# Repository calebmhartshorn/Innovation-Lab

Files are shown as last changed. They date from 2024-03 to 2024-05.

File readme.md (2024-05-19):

# QuarterMaster
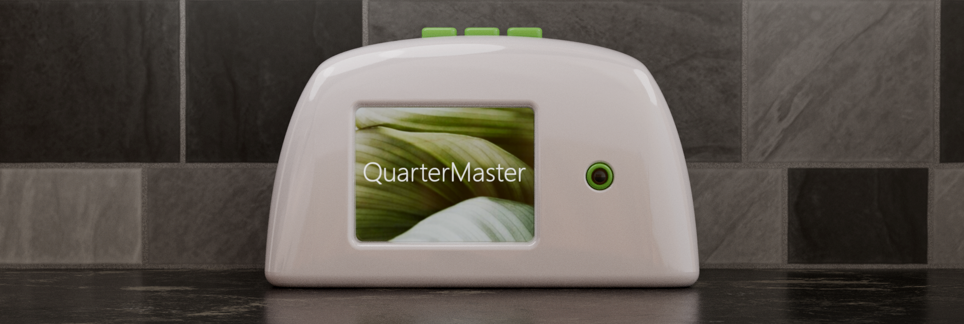
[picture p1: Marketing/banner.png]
QuarterMaster Banner Image

QuarterMaster is a smart kitchen device used to track grocery inventory, expiration dates, and suggest recipes to minimize food waste.

More details can be found at our [website](https://oliverstratford23.wixsite.com/quartermaster).

### QuarterMaster Repository Structure
Current development work is organized as follows:

| Directory | Info |
|--|--|
| `/App` | Holds all server-side files for the Raspberry Pi |
| `/App/website` | Holds all client-side web app files |
| `/CAD` | Holds any CAD and STL files, parts lists, and assembly instructions. |
| `/Marketing` | Holds marketing briefs, website files, blender files/renders, etc. |

### Client and Server Info
The physical scanner device, running on a RPi, hosts a local HTTP webserver allowing clients to connect directly via IP address on port 8000.
For example, if the RPi's local IP address was 192.168.0.14, another device on the same network could access the webclient via http://192.168.0.14:8000. Note this does not work on networks with certain firewalls/restrictions (notably including Bath Spa `eduroam` and similar networks, depending on subdomain allocations). It is expected to work on most home networks.

> **Note:** Port number may be redefined in server.py

For reference during development, the following figure summarizes the platforms, languages, and responsibilities of each entity.

|| Client | Server |
|--|--|--|
| **Platform** | Mobile/Desktop Browser | Raspberry Pi 5 |
| **Languages** | <li>HTML</li><li>CSS</li><li>JS</li> | Python
| **Features** |<li>Inventory Viewing</li><li>Recipe Viewing</li> | <li>Scan Items In</li><li>Scan Items Out</li>

### Communications Protocol
Client ↔ Server communication uses HTTP protocol. Specifically, GET and POST requests are made by the client.
> This functionality is implemented in `/App/server.py` and `/App/website/client.js`

| Type | Path | Body | Response Content Type| Response | Note|
|--|--|--|--|--|--|
| `GET` | `/index.html` | |  `text/html`  | `index.html` file |
| `GET` | `/styles.css` || `text/css`  | `styles.css` file |
| `GET` | `/client.js` | |`application/javascript`  | `client.js` file |
| ... | ... | ... | ... | ...| Continued for any additional plain files
| `GET` | `/inventory` || `application/javascript` | JSON inventory data | |
| `GET` | `/recipe/*` || `application/javascript` | Makes request to Tesco API and returns result. | See `server.py` line 180-225 for additional parameter details.
| `POST` | `/update-inventory` | Updated JSON inventory data | `text/html` | Status Message | Current web app version does not implement this functionality.

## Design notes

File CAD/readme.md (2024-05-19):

## CAD

STL files for product model.

Exportable CAD files can be viewed on [OnShape](https://cad.onshape.com/documents/a9ea1d888f3dee972e6036d2/w/ec1619c3bd35b931f617c110/e/a813004631bccc3c93063bfe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)

### Assembly Instructions:

After all the parts have been printed using the given STLs the assembly proccess can begin

Step #1: Attach the screen to the mounting frame using the smaller bushings with a nylon nut and bolt.

Step #2: Connect the screen to the Raspberry Pi following the screens wiki page (https://www.waveshare.com/wiki/2.4inch_LCD_Module).

Step #3: Attach the camera to the mounting frame using the longer bushing with a nylon nut and bolt.

Step #4: Attach the camera cable adapter to the Raspberry Pi using the camera port 0, and the camera

Step #5: Ensure the SD card has been placed within the Raspberry Pi.

Step #6: Thread a screw through the back casing, the Raspberry Pi, and mounting frame and secure this with a nut. 

Step #7: Next, clip the buttons into there slot, located at the top of the back casing. 

Step #8: Wire these buttons into GPIO ports 14, 15, and 17.

Step #9: The printed buttons can then be glued onto these buttons.

Step #10: Place a nylon nut in each cut out in the front casing.

Step #11: Thread a screw through the back of the back casing into the nylon nut of the front casing to secure the whole product together. 

### Components:

Screen: https://thepihut.com/products/2-4-lcd-display-module-240x320

SD Card: https://www.samsung.com/uk/memory-storage/memory-card/evo-plus-microsd-card-64gb-mb-mc64sa-eu/

Camera Adapter Cable: https://thepihut.com/products/camera-adapter-cable-for-raspberry-pi-5?variant=42531560784067

Camera: https://www.amazon.co.uk/gp/product/B076FB1KCW/ref=ox_sc_act_title_2?smid=A1X7QLRQH87QA3&th=1

Buttons: https://thepihut.com/products/soft-silicone-top-6mm-push-buttons-20-pack?variant=19932900720702

Nuts: https://thepihut.com/products/nylon-nut-m2-5?variant=20063144869950

Screws: https://thepihut.com/products/nylon-slotted-cheese-head-screws-m2-5-x-20mm?variant=20063144935486

Cables: https://www.amazon.co.uk/AZDelivery-Pieces-Jumper-Arduino-Raspberry/dp/B074P726ZR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

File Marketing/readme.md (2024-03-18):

### Marketing

Keep any files for marketing material here. This includes logos, website files, etc.

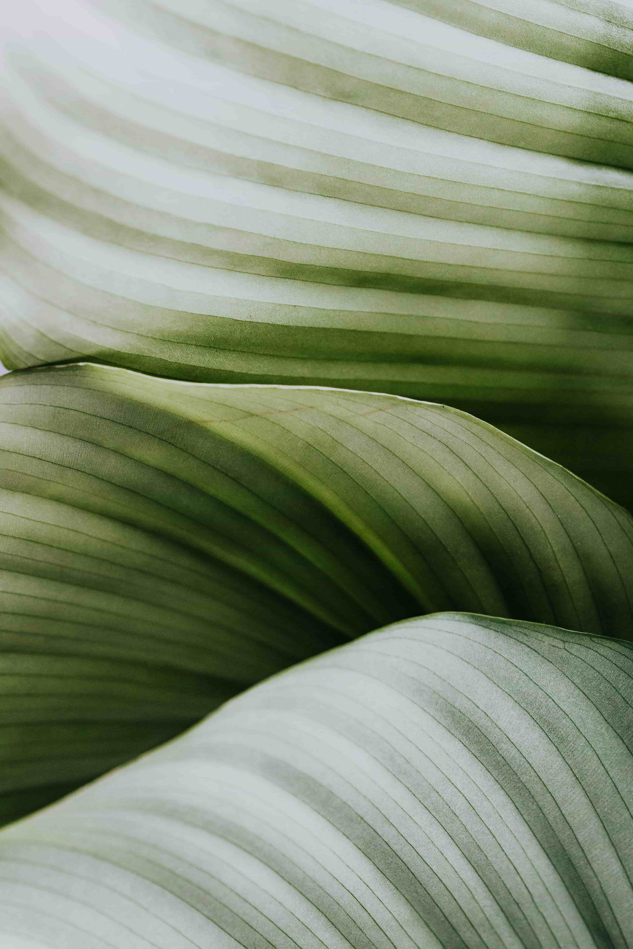
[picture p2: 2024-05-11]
App/website/assets/leaf.jpg

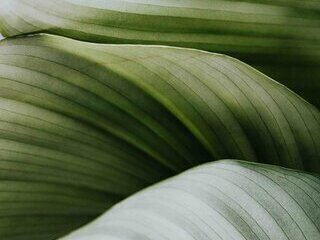
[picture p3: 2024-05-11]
App/leaf_320x240.jpg

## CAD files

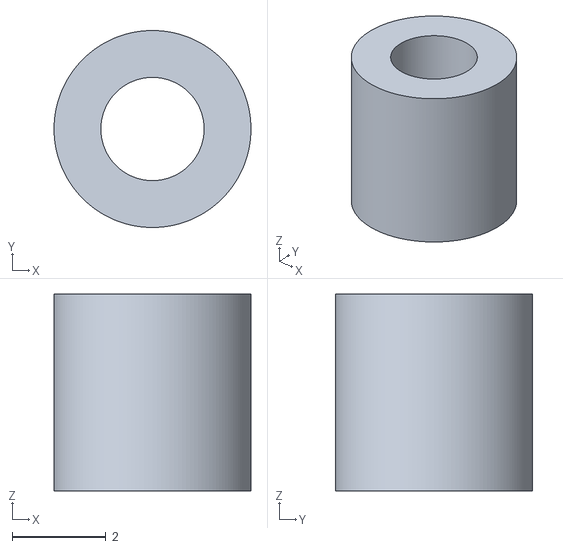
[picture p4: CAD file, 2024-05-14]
CAD/2x_Bushing_2.2x4.2.stl
4.20 x 4.20 x 4.20

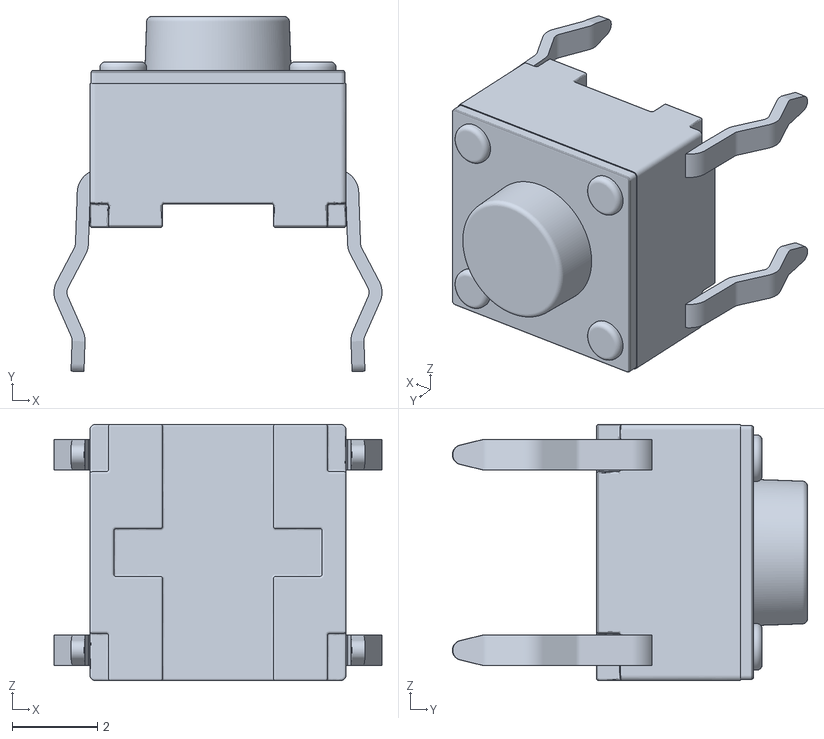
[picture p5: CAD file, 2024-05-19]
CAD/electronics/tactileswitch-short.stl
7.69 x 8.33 x 6.01

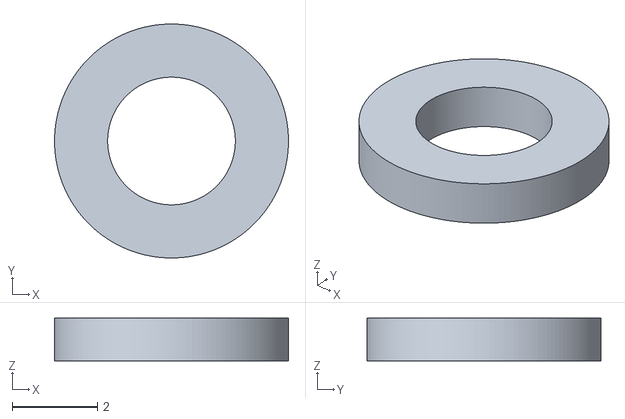
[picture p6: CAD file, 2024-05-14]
CAD/4x_Bushing_3.0x1.0.stl
5.50 x 5.50 x 1.00

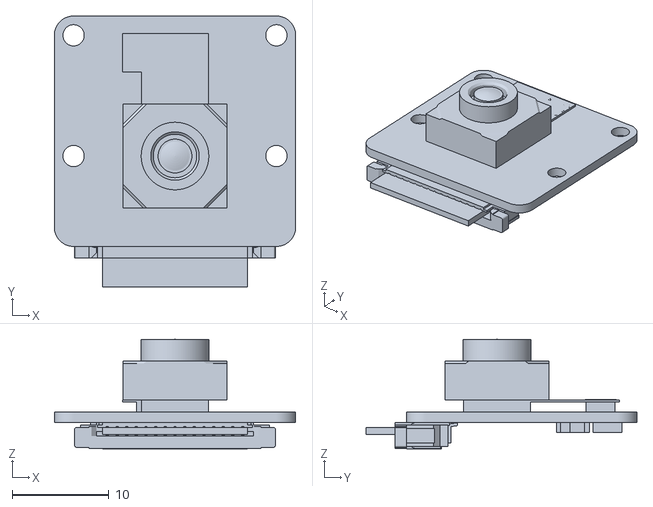
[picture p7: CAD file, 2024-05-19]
CAD/electronics/Camera Moudule 3 v8 (1).stl
25.0 x 28.1 x 11.3

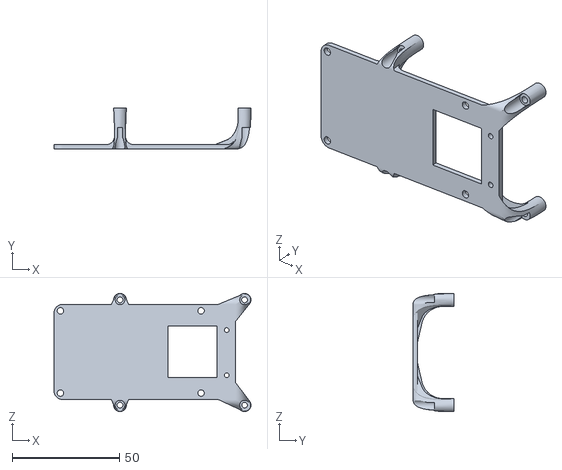
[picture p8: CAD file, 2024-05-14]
CAD/1x_Mounting_Frame.stl
91.7 x 19.1 x 55.0

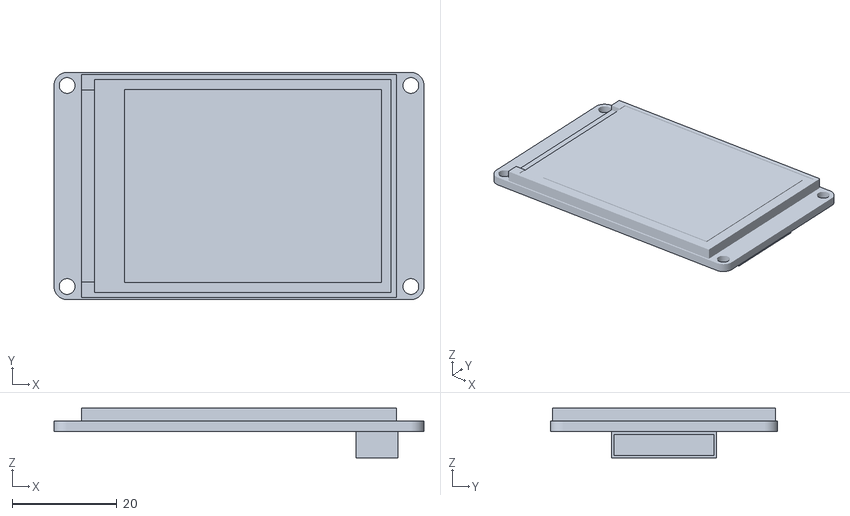
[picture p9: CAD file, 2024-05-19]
CAD/electronics/LCD.stl
70.5 x 43.3 x 9.50

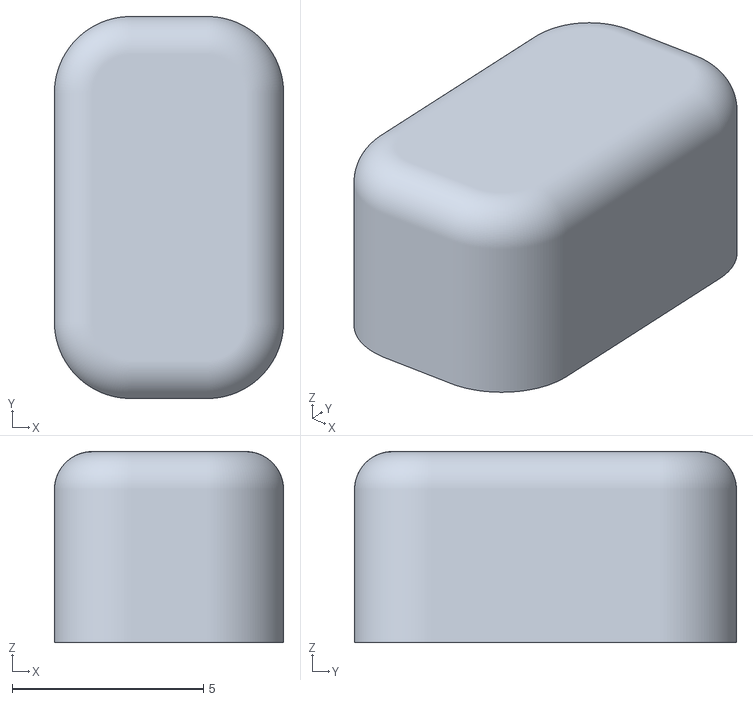
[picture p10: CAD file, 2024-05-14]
CAD/3x_Button.stl
6.00 x 10.0 x 5.00

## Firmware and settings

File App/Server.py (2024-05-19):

# import OS and set environment variables
import os
os.environ['XDG_RUNTIME_DIR'] = '/tmp/runtime-user/' # Set root working dir
os.environ['LIBCAMERA_LOG_LEVELS'] = '4'             # Hide libcamera logs
os.environ['PYGAME_HIDE_SUPPORT_PROMPT'] = '1'       # Hide pygame messages

# Default Libs
import time, datetime, threading, http.server, socketserver, json, logging, requests
from urllib.parse import urlparse, parse_qs

# Non-default Libs
import cv2                                   # OpenCV - For vision processing 
from pyzbar.pyzbar import decode, ZBarSymbol # Pyzbar - For barcode reading
from picamera2 import Picamera2              # Picamera2 - RPi Camera drivers
import pygame                                # pygame - For sound effects

# Local files
from gui_app import App, State

# Setup logging
logger = logging.getLogger('simple_example')
logger.setLevel(logging.DEBUG)
console = logging.StreamHandler()
console.setLevel(level=logging.DEBUG)
formatter =  logging.Formatter('%(levelname)s : %(message)s')
console.setFormatter(formatter)
logger.addHandler(console)

# Globals
HTTP_SERVER_PORT = 8000

inventory = {}
app = None

def add_quantity(barcode):
    barcode = str(barcode)
    scanned_date = datetime.datetime.now().strftime("%Y-%m-%d")
    
    if barcode in inventory:
        inventory_entry = inventory[barcode]
        inventory_entry['scans'].append(scanned_date)
    else:
        inventory[barcode] = {
            "name": "Unknown",
            "generic_name": "Unknown",
            "size": 1,
            "size_units": "Unit",
            "shelf_life": 7,
            "scans": [scanned_date]
        }

    with open('inventory.json', 'w') as f:
        json.dump(inventory, f, indent=2)
    app.init_main_scanned_state(barcode)

def remove_quantity(barcode):
    barcode = str(barcode)    
    if barcode in inventory:
        inventory_entry = inventory[barcode]
        if len(inventory_entry['scans']) > 0:
            inventory_entry['scans'].pop(0)
            with open('inventory.json', 'w') as f:
                json.dump(inventory, f, indent=2)
    app.init_scan_out_scanned_state(barcode)
    
def decode_barcode_from_webcam():
    global app

    cv2.namedWindow('image',cv2.WINDOW_GUI_NORMAL)
    
    Picamera2.set_logging(Picamera2.ERROR)
    picam2 = Picamera2()
    
    config = picam2.create_still_configuration(
        main = {"size": picam2.sensor_resolution}
    )
    picam2.configure(config)
    picam2.set_controls({"ExposureTime": 5000, "AnalogueGain": 50.0})
    picam2.start()
    
    pygame.mixer.pre_init(frequency=44100, size=-16, channels=2)
    pygame.mixer.init()
    sound = pygame.mixer.Sound('blip-131856.mp3')
    
    while True:
        if app.state == State.SLEEP:
            continue

        frame = picam2.capture_array()

        scale = 0.2
        width = int(frame.shape[1] * scale)
        height = int(frame.shape[0] * scale)
        frame = cv2.resize(frame, (width, height))
        
        frame = cv2.cvtColor(frame, cv2.COLOR_BGR2GRAY)
        
        decoded_objects = decode(frame, symbols=[ZBarSymbol.EAN8])

        for obj in decoded_objects:
            barcode = obj.data.decode('utf-8')

            try:
                barcode_int = int(barcode)
            except ValueError:
                print(f"Invalid barcode: {barcode}")
                continue


            try:
                if app.state == State.MAIN:
                    add_quantity(barcode_int)
                    app.no_input_ts = datetime.datetime.now()
                    playing = sound.play()
                    time.sleep(.5)
                elif app.state == State.SCAN_OUT:
                    remove_quantity(barcode_int)
                    app.no_input_ts = datetime.datetime.now()                    
                    playing = sound.play()
                    time.sleep(.5)
            except Exception as e:
                print(f"Error adding barcode to inventory: {e}")

            cv2.rectangle(frame, (obj.rect.left, obj.rect.top),
                          (obj.rect.left + obj.rect.width, obj.rect.top + obj.rect.height),
                          (0, 255, 0), 2)
            cv2.putText(frame, str(barcode_int), (obj.rect.left, obj.rect.top - 10),
                        cv2.FONT_HERSHEY_SIMPLEX, 0.5, (0, 0, 255), 2)

        cv2.imshow('image', frame)

        if cv2.waitKey(1) & 0xFF == 27:
            break

    cv2.destroyAllWindows()

class MyHTTPRequestHandler(http.server.SimpleHTTPRequestHandler):
    def set_common_headers(self):
        self.send_header('Access-Control-Allow-Origin', '*')
        self.send_header('Access-Control-Allow-Methods', 'GET, POST, OPTIONS')
        self.end_headers()
    def do_GET(self):
        global inventory
        print("Received GET request")
        try:
            if self.path == '/':
                self.send_response(200)
                self.send_header('Content-type', 'text/html')
                self.end_headers()
                with open('website/index.html', 'rb') as f:
                    self.wfile.write(f.read())
            elif self.path == '/client.js':
                self.send_response(200)
                self.send_header('Content-type', 'text/javascript')
                self.end_headers()
                with open('website/client.js', 'rb') as f:
                    self.wfile.write(f.read())
            elif self.path == '/styles.css':
                self.send_response(200)
                self.send_header('Content-type', 'text/css')
                self.end_headers()
                with open('website/styles.css', 'rb') as f:
                    self.wfile.write(f.read())
            elif self.path == '/Assets/leaf.jpg':
                self.send_response(200)
                self.send_header('Content-type', 'text/javascript')
                self.end_headers()
                with open('website/assets/leaf.jpg', 'rb') as f:
                    self.wfile.write(f.read())
            elif self.path == '/inventory':
                print("Received request for inventory data")
                self.send_response(200)
                self.send_header('Content-type', 'application/json')
                self.end_headers()
                inventory_data = json.dumps(inventory).encode()
                print(f"Sending inventory data")
                self.wfile.write(inventory_data)


            elif self.path.startswith("/recipe"):
                # Parse the URL
                parsed_url = urlparse(self.path)
                
                # Extract the query parameters
                params = parse_qs(parsed_url.query)
                
                # Now you can access the parameters as a dictionary
                ingredients =          params.get('ingredients',['[]'])[0].replace("[", "").replace("]", "").split(",")
                mandatoryIngredients = params.get('must', [])
                if mandatoryIngredients:
                    mandatoryIngredients = [mandatoryIngredients[0]]
                else:
                    mandatoryIngredients = []  # Set it to an empty list if 'must' is not in the query

                url = 'https://realfood.tesco.com/api/ingredientsearch/getrecipes'
                
                data = {
                    # These are a harcoded example. Anything is fine, but make to use at least 3 ingredients and only use terms defined
                    # in ingredients.txt
                    'ingredients': ingredients,
                    'mandatoryIngredients': mandatoryIngredients,
                    'dietaryRequirements': []
                }
                response = requests.post(url, json=data)

                json_data = response.json()
                print(json.dumps(json_data, indent=2))

                # Just names
                response = ""
                for recipe in json_data['results']:
                    name = recipe['recipeName']
                    response += f"<p>{name}</p>"
                    #print(f"{name}")
                self.send_response(200)
                self.send_header('Content-type', 'application/json')
                self.set_common_headers()
                self.wfile.write(json.dumps(json_data).encode())


            else:
                super().do_GET()
        except Exception as e:
            print(f"Error in do_GET: {e}")
            self.send_error(500, str(e))

    def do_POST(self):
        try:
            if self.path == '/update-inventory':
                content_length = int(self.headers['Content-Length'])
                post_data = self.rfile.read(content_length)
                updated_inventory = json.loads(post_data.decode('utf-8'))
                global inventory
                inventory = updated_inventory
                self.send_response(200)
                self.send_header('Content-type', 'text/plain')
                self.end_headers()
                self.wfile.write(b'Inventory updated successfully')
            else:
                super().do_POST()
        except Exception as e:
            print(f"Error in do_POST: {e}")
            self.send_error(500, str(e))

def main():
    global inventory, app
    
    # Read in inventory
    if os.path.exists('inventory.json'):
        with open('inventory.json', 'r', encoding='UTF-8') as f:
            inventory = json.load(f)
    else:
        print("File 'inventory.json' not found. Creating a new one.")
        inventory = {}
    class MyTCPServer(socketserver.TCPServer):
        allow_reuse_address = True
    with MyTCPServer(("", HTTP_SERVER_PORT), MyHTTPRequestHandler) as httpd:
        # Instantiate GUI app
        app = App(logger, inventory)
        
        # Create thread objects
        app_thread = threading.Thread(target=app.start)
        http_server_thread = threading.Thread(target=httpd.serve_forever)
        
        # Start threads
        app_thread.start()
        http_server_thread.start()

        decode_barcode_from_webcam()

        # Terminate & join remaining threads
        app.shutdown()
        httpd.shutdown()
        app_thread.join()
        http_server_thread.join()

if __name__ == "__main__":
    main()

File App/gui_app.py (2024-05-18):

#!/usr/bin/python
# -*- coding: UTF-8 -*-
#import chardet
import sys, logging, math, time
from enum import Enum
from datetime import datetime, timedelta
import os
# Gets the current user's home directory so it could be pi or Matt or whatever
home_dir = os.path.expanduser('~')
lg_folder = os.path.join(home_dir, 'lg-master', 'LCD_Module_RPI_code', 'RaspberryPi', 'python')
sys.path.append(lg_folder)
from lib import LCD_2inch4
import gpiozero
from PIL import Image,ImageDraw,ImageFont, ImageEnhance
import queue  # Import the queue module


class State(Enum):
    WELCOME = 0
    MAIN = 1
    SCAN_OUT = 2
    MAIN_SCANNED = 3
    SCAN_OUT_SCANNED = 4
    SLEEP = 5

class App():

    def __init__(self, logger, inventory):

        self.logger = logger    
        self.inventory = inventory

        # LCD pins
        RST = 27
        DC = 25
        BL = 18
        bus = 0 
        device = 0
        
        self.lcd = LCD_2inch4.LCD_2inch4()

        # Initialize library.
        self.lcd.Init()



        # Setup buttons
        PIN_BTN_LEFT = 15
        PIN_BTN_RIGHT = 17
        PIN_BTN_MIDDLE = 14
        self.btn_left = gpiozero.Button(PIN_BTN_LEFT, bounce_time=0.05)
        self.btn_right = gpiozero.Button(PIN_BTN_RIGHT, bounce_time=0.05)
        self.btn_middle = gpiozero.Button(PIN_BTN_MIDDLE, bounce_time=0.05)
        self.commands_queue = queue.Queue()  # Define a queue for commands

        self.btn_left.when_pressed = lambda: self.commands_queue.put(('left',))
        self.btn_right.when_pressed = lambda: self.commands_queue.put(('right',))
        self.btn_middle.when_pressed = lambda: self.commands_queue.put(('middle',))

        self.is_btn_left_just_pressed = False
        self.is_btn_right_just_pressed = False
        self.is_btn_middle_just_pressed = False

        self.no_input_ts = datetime.now()

        self.font1 = ImageFont.truetype("Font00.ttf",48)

        self.exit = False

        self.init_welcome_state()

    def init_welcome_state(self):
        self.state = State.WELCOME
        self.welcome_text_y = 240
        self.welcome_start_ts = datetime.now()

        #Set the backlight to 100
        self.lcd.bl_DutyCycle(100)
#        self.lcd.clear()

    def init_main_state(self):
        self.state = State.MAIN
        self.menu_scroll_position = 0
        self.menu_cursor_position = 0
        self.no_input_ts = datetime.now()

    def init_scan_out_state(self):
        self.state = State.SCAN_OUT

    def init_main_scanned_state(self, barcode):
        self.state = State.MAIN_SCANNED
        self.scanned_item_name = self.inventory[barcode]["name"]
        self.scanned_start_ts = datetime.now()

    def init_scan_out_scanned_state(self, barcode):
        self.state = State.SCAN_OUT_SCANNED
        self.scanned_item_name = self.inventory[barcode]["name"]
        self.scanned_start_ts = datetime.now()

    def init_sleep_state(self):
        self.state = State.SLEEP
        #Set the backlight to 0
        self.lcd.bl_DutyCycle(0)

    def start(self):
        while self.exit == False:
            self.update_inputs()
            self.update()
            self.render()
    
    def shutdown(self):
        self.exit = True
    
    def update_inputs(self):
        self.is_btn_left_just_pressed = False
        self.is_btn_right_just_pressed = False
        self.is_btn_middle_just_pressed = False
        while not self.commands_queue.empty(): 
            self.no_input_ts = datetime.now()
            command = self.commands_queue.get()
            if command[0] == 'left':
                self.is_btn_left_just_pressed = True
            elif command[0] == 'right':
                self.is_btn_right_just_pressed = True
            elif command[0] == 'middle':
                self.is_btn_middle_just_pressed = True
        self.sec_since_last_input = (datetime.now() - self.no_input_ts).seconds

    def update(self):
        match self.state:
            case State.WELCOME:
                self.welcome_text_y += (120 - self.welcome_text_y) * 0.25
                ellapsed_time = datetime.now() - self.welcome_start_ts
                if ellapsed_time.seconds > 1:
                    self.init_main_state()
            case State.MAIN:
                if self.is_btn_left_just_pressed:
                    self.menu_cursor_position -= 1  # Move up in the list
                    if self.menu_cursor_position < 0:
                        self.menu_cursor_position = 0  # Ensure the position doesn't go below 0
                    if self.menu_scroll_position > self.menu_cursor_position:
                        self.menu_scroll_position = self.menu_cursor_position
                if self.is_btn_right_just_pressed:
                    self.menu_cursor_position += 1  # Move down in the list
                    length = len(self.process_items())
                    if self.menu_cursor_position > length - 1:
                        self.menu_cursor_position = length - 1
                    if self.menu_scroll_position + 4 < self.menu_cursor_position:
                        self.menu_scroll_position = self.menu_cursor_position - 4
                if self.is_btn_middle_just_pressed:
                    self.init_scan_out_state()
                if self.sec_since_last_input > 60:
                    self.init_sleep_state()
            case State.SCAN_OUT:
                if self.is_btn_middle_just_pressed or \
                   self.is_btn_left_just_pressed or \
                   self.is_btn_right_just_pressed:
                    self.init_main_state()
            case State.MAIN_SCANNED:
                elapsed_time = datetime.now() - self.scanned_start_ts
                if elapsed_time.seconds > 0.5:
                    self.init_main_state()
            case State.SCAN_OUT_SCANNED:
                elapsed_time = datetime.now() - self.scanned_start_ts
                if elapsed_time.seconds > 0.5:
                    self.init_scan_out_state()
            case State.SLEEP:
                if self.sec_since_last_input < 60:
                    self.init_welcome_state()

    def render(self):
        match self.state:
            case State.WELCOME:
                image = Image.open('leaf_320x240.jpg')
                enhancer = ImageEnhance.Brightness(image)
                # to reduce brightness by 50%, use factor 0.5
                image = enhancer.enhance(0.5)#translate(self.welcome_text_y, 240, 120, 1.0, 0.5))
                draw = ImageDraw.Draw(image)
                
                txt = Image.new("RGBA", image.size, (255, 255, 255, 0))
                b = ImageDraw.Draw(txt)
                b.multiline_text(
                    (160, self.welcome_text_y), 
                    'Welcome', 
                    fill = (255,255,255,255-round(self.welcome_text_y-120)*3),
                    font=self.font1,
                    anchor='mm')
                
                image = Image.alpha_composite(image.convert("RGBA"), txt)
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

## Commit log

2024-01-28 Added Example JSON Structure
    This JSON file was designed to help unify our text programs, supporting all of our current design requirements.
    All future work should conform to this document.
2024-01-28 Added API Support for Future Scanning Integration
    Added functionality for the client to ask the server to start scanning, which runs in a seperate thread on the server and sends back results every 0.5 sec.
    Currently, the results it sends back are dummy random values, but it should be reasonably easy to integrate Matthew's OCR work now.
2024-01-28 [Matthew] Added Clear All Button
2024-03-18 Create CAD
2024-03-18 Updated CAD file structure
2024-03-20 Fixed Add Quantity Call
    [Server.py]
2024-03-23 Update Server.py
    Fixed some date issues
    [Server.py]
2024-03-27 Updated Data Structure - WIP/Client Server needs corrections!
    [Server.py]
2024-05-11 Picamera2 & LCD Integration, etc. (see description)
    - Updated code to use Picamera2 instead of CV2.videoCapture. This is required for new camera hardware.
    - Optimized image and PyZBar config for faster detection.
    - Refactored server.py in prep for upcoming features and improved readability.
    - Added gui_app.py for interface (LCD + Buttons) - Mostly boilerplate for now.
    - Moved web files into "website" dir.
    - Compressed image files for faster website loading times.
    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
2024-05-12 Test Commit From Raspberry Pi
2024-05-12 Adding the CAD STLs
    [1x_Mounting_Frame.stl, 2x_Bushing_2.2x4.2.stl]
2024-05-13 Added Missing CAD STL Files
    [3x_Button.stl, 4x_Bushing_3.0x1.0.stl]
2024-05-14 Added Initial Scan-out Functionality
    - Fixed button synchronisation
    - Better menu design w/ cursor
    - Scanout GUI state and navigation
    - Basic scanout functinality from `server.py`
    [Server.py, gui_app.py]
2024-05-14 Added SLEEP State
    - Sleeps automatically after 5 secs (short for testing purposes)
    - Disable camera when asleep
    - Minor improvements to scan timings
    [Server.py, gui_app.py]
2024-05-19 Added Electronics 3D Models
    [Camera Moudule 3 v8 (1).stl, LCD.stl, tactileswitch-short.stl]
2024-05-19 Updated CAD readme with Assembly instructions and Component list
2024-05-19 Update CAD readme.md
2024-05-19 Update CAD readme.md
